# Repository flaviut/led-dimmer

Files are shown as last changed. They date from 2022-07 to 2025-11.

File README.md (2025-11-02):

# IoT RGBWW strip dimmer

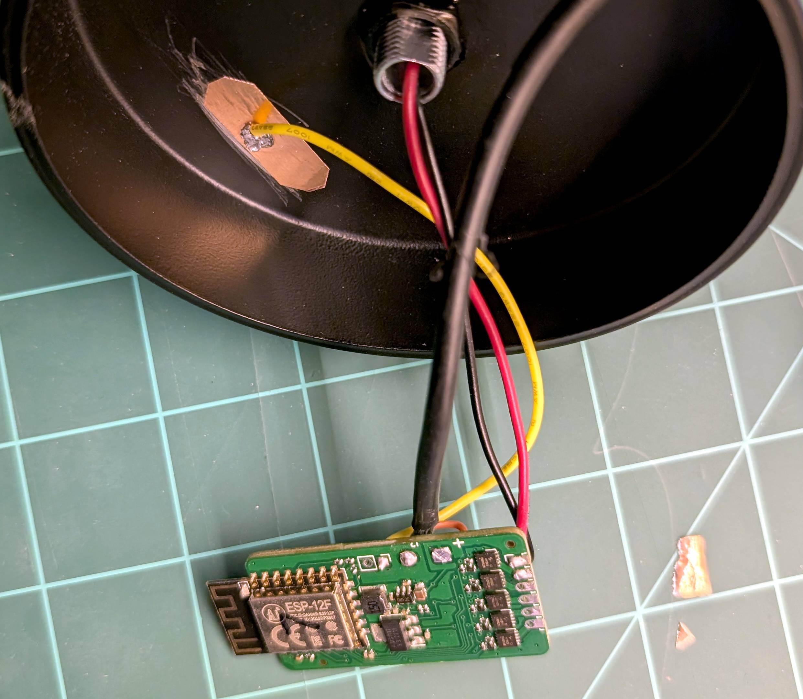
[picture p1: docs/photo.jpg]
photo of dimmer


Designed for use with ESPHome, this project is a compact & powerful dimmer for all LED strips. The primary goal was low cost, in the most compact package possible. For scale, the picture above was taken on a 1 inch grid.

This is intended as a substitute for the poorly-designed Magic Home LED strip controllers.

Note: the yellow wire in the photo does not work as a capacitive touch sensor, that was a failed experiment.

## Features

- Up to 5 lighting channels
- Support for voltages between 5V and 24V
- Up to 4A per channel. Outputs can be paralleled.
- Reasonable efficiency: approx. 200mW standby power draw.
- Low cost, PCB is about $6/ea manufactured at qty 10, or about $4.30/ea at qty 30.

## Description

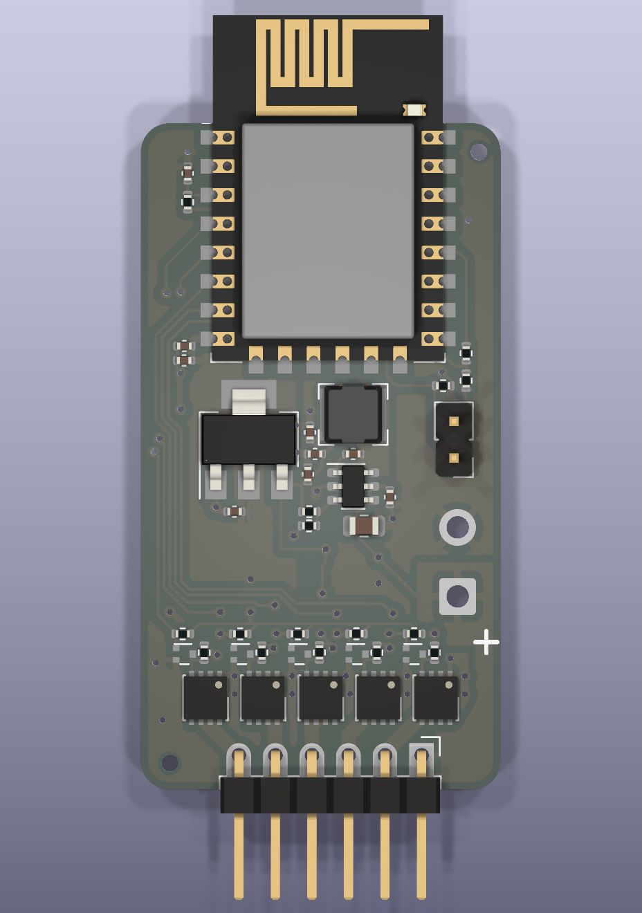
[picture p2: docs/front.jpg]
front

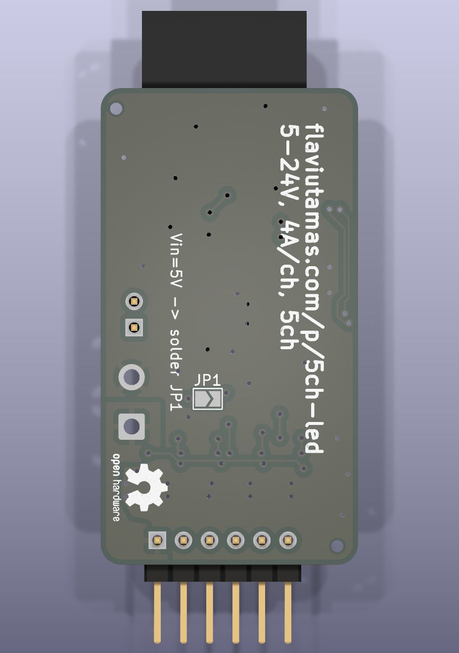
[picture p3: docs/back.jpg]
back

[Schematic](./docs/schematic.pdf)

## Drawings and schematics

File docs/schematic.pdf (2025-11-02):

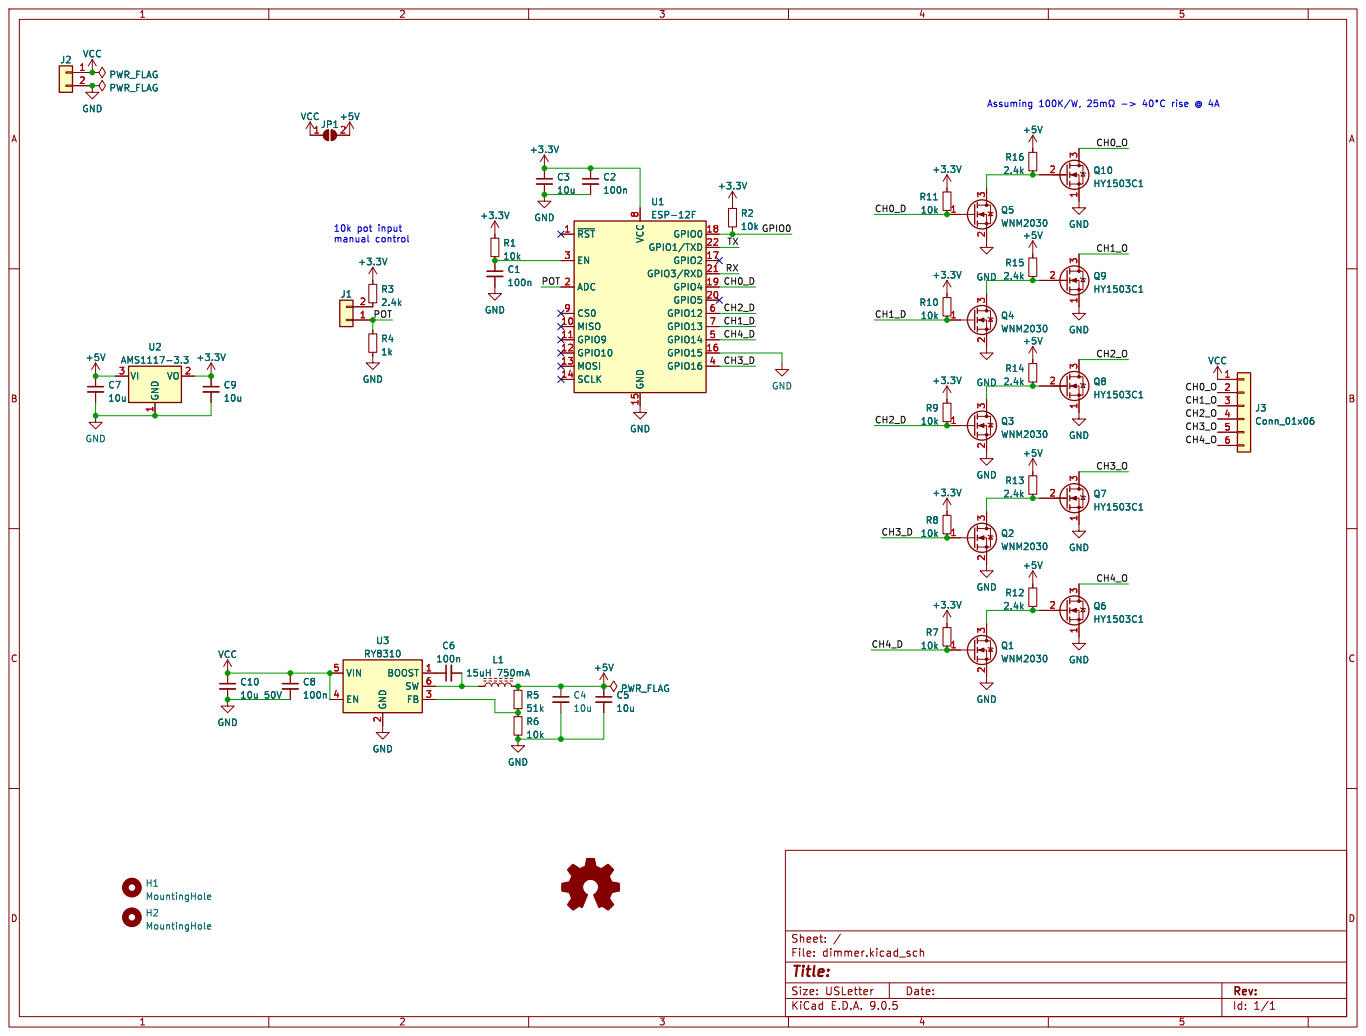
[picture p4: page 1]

Id: 1/1 Title: File: dimmer.kicad_sch Sheet: /

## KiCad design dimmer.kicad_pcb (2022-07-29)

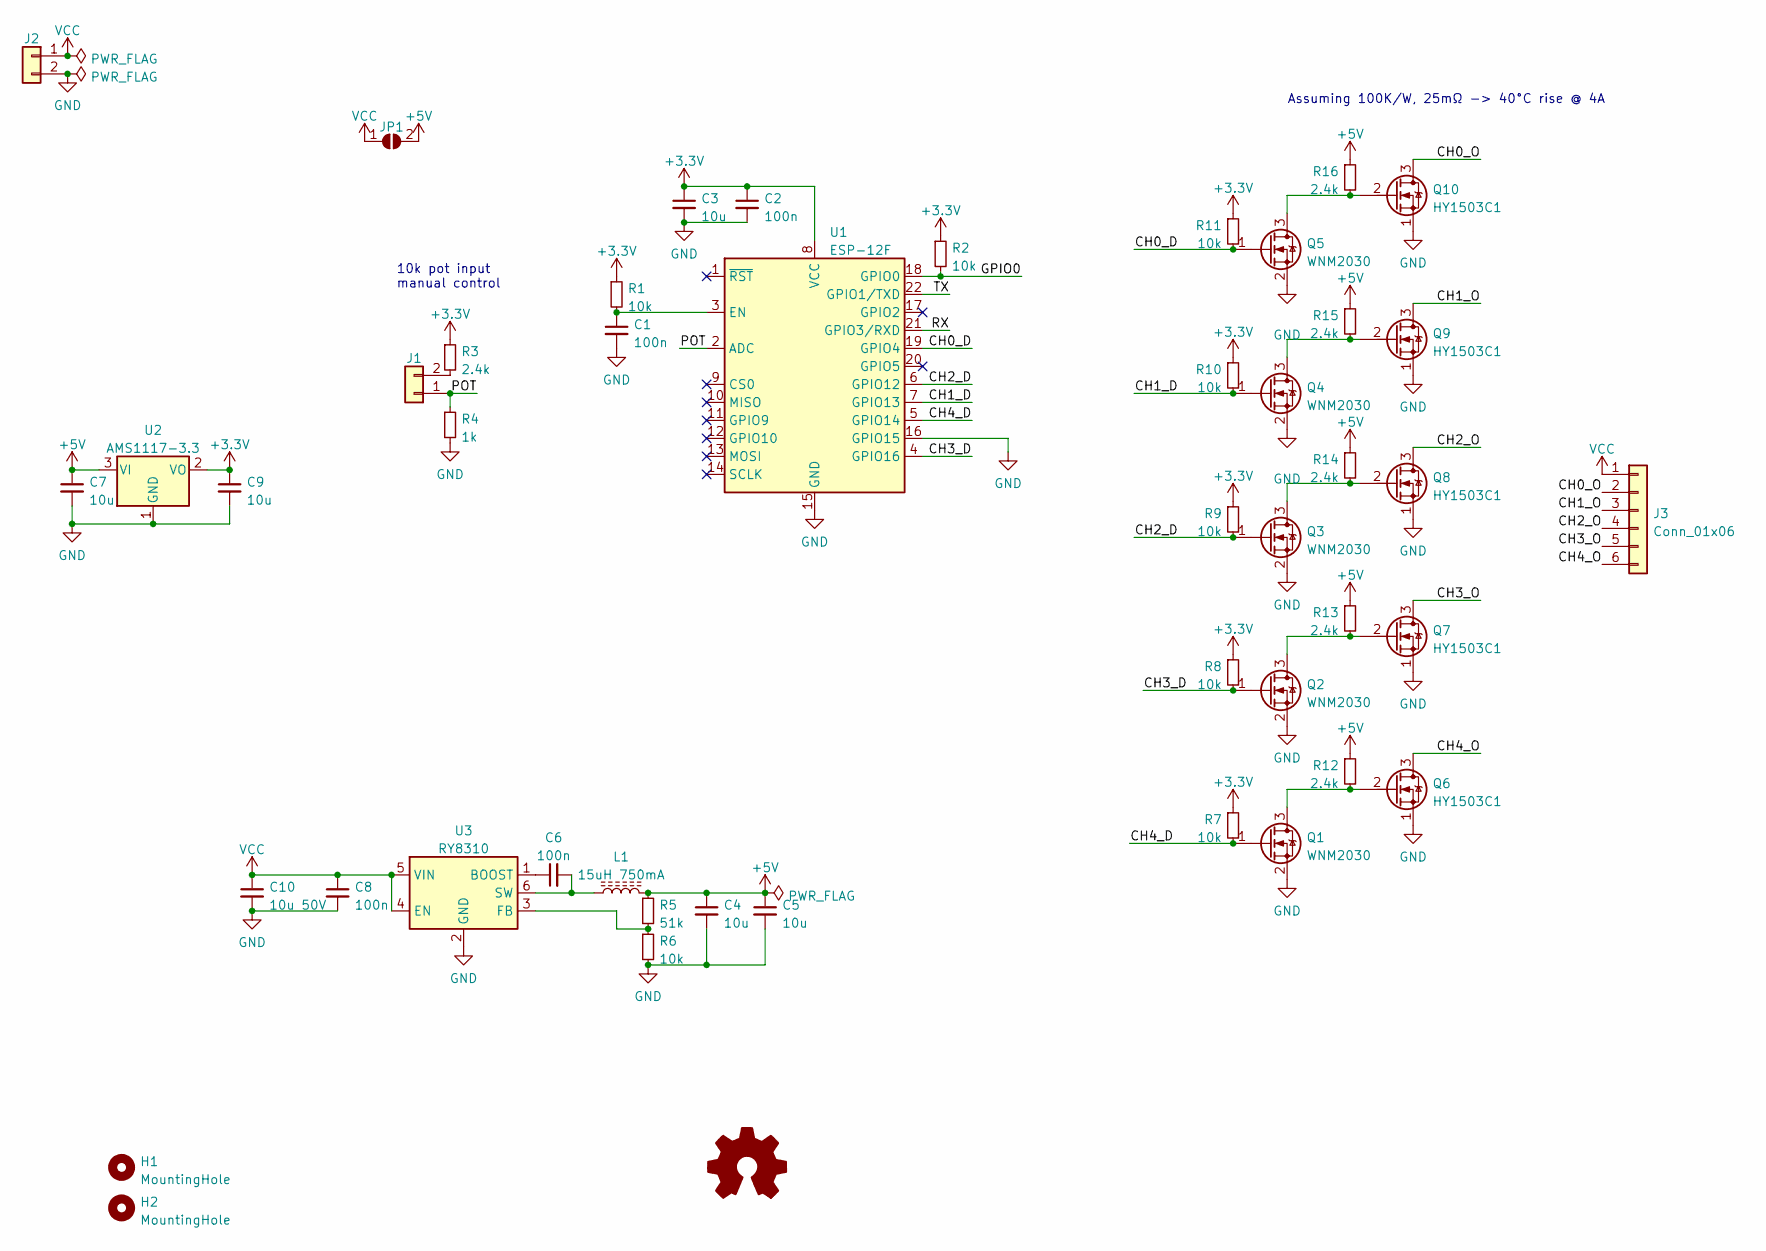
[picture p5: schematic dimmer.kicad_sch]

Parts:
C1, C2, C6, C8: 100n; C_0402_1005Metric; LCSC C307331
C3, C4, C5, C7, C9: 10u; C_0402_1005Metric; LCSC C15525
C10: 10u 50V; C_0805_2012Metric; LCSC C440198
H1, H2: MountingHole; ToolingHole
J1: Conn_01x02; PinHeader_1x02_P2.54mm_Vertical
J2: Conn_01x02; SolderWire-0.75sqmm_1x02_P4.8mm_D1.25mm_OD2.3mm
J3: Conn_01x06; PinHeader_1x06_P2.54mm_Horizontal
JP1: SolderJumper_2_Open; SolderJumper-2_P1.3mm_Open_TrianglePad1.0x1.5mm
L1: 15uH 750mA; L_Bourns-SRN4018; LCSC C167837
LOGO1: Logo_Open_Hardware_Small; OSHW-Logo2_7.3x6mm_SilkScreen
Q1, Q2, Q3, Q4, Q5: WNM2030; SOT-723; LCSC C239769
Q6, Q7, Q8, Q9, Q10: HY1503C1; DFN-8-1EP_3x3mm_P0.65mm_EP2x2.4mm; LCSC C315567
R1, R2, R6, R7, R8, R9, R10, R11: 10k; R_0402_1005Metric; LCSC C25744
R3, R12, R13, R14, R15, R16: 2.4k; R_0402_1005Metric; LCSC C25882
R4: 1k; R_0402_1005Metric; LCSC C11702
R5: 51k; R_0402_1005Metric; LCSC C25794
U1: ESP-12F; ESP-12E; LCSC C82891
U2: AMS1117-3.3; SOT-223-3_TabPin2; LCSC C6186
U3: RY8310; TSOT-23-6; LCSC C370876

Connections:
+3.3V: C2.1, C3.1, C9.1, R1.1, R2.1, R3.1, R7.1, R8.1, R9.1, R10.1, R11.1, U1.8 (VCC), U2.2 (VO)
+5V: C4.1, C5.1, C7.1, JP1.2 (B), L1.2, R5.1, R12.1, R13.1, R14.1, R15.1, R16.1, U2.3 (VI)
/CH0_D: Q5.1 (G), R11.2, U1.19 (GPIO4)
/CH0_O: J3.2, Q10.3 (D)
/CH1_D: Q4.1 (G), R10.2, U1.7 (GPIO13)
/CH1_O: J3.3, Q9.3 (D)
/CH2_D: Q3.1 (G), R9.2, U1.6 (GPIO12)
/CH2_O: J3.4, Q8.3 (D)
/CH3_D: Q2.1 (G), R8.2, U1.4 (GPIO16)
/CH3_O: J3.5, Q7.3 (D)
/CH4_D: Q1.1 (G), R7.2, U1.5 (GPIO14)
/CH4_O: J3.6, Q6.3 (D)
/GPIO0: R2.2, U1.18 (GPIO0)
/POT: J1.1, R4.1, U1.2 (ADC)
/RX: U1.21 (GPIO3/RXD)
/TX: U1.22 (GPIO1/TXD)
GND: C1.2, C2.2, C3.2, C4.2, C5.2, C7.2, C8.2, C9.2, C10.2, J2.2, Q1.2 (S), Q2.2 (S), Q3.2 (S), Q4.2 (S), Q5.2 (S), Q6.1 (S), Q7.1 (S), Q8.1 (S), Q9.1 (S), Q10.1 (S), R4.2, R6.2, U1.15 (GND), U1.16 (GPIO15), U2.1 (GND), U3.2 (GND)
unnamed: C1.1, R1.2, U1.3 (EN)
unnamed: C6.1, U3.1 (BOOST)
unnamed: C6.2, L1.1, U3.6 (SW)
unnamed: J1.2, R3.2
unnamed: Q1.3 (D), Q6.2 (G), R12.2
unnamed: Q2.3 (D), Q7.2 (G), R13.2
unnamed: Q3.3 (D), Q8.2 (G), R14.2
unnamed: Q4.3 (D), Q9.2 (G), R15.2
unnamed: Q5.3 (D), Q10.2 (G), R16.2
unnamed: R5.2, R6.1, U3.3 (FB)
VCC: C8.1, C10.1, J2.1, J3.1, JP1.1 (A), U3.4 (EN), U3.5 (VIN)

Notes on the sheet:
Assuming 100K/W, 25mΩ -> 40°C rise @ 4A
10k pot input manual control

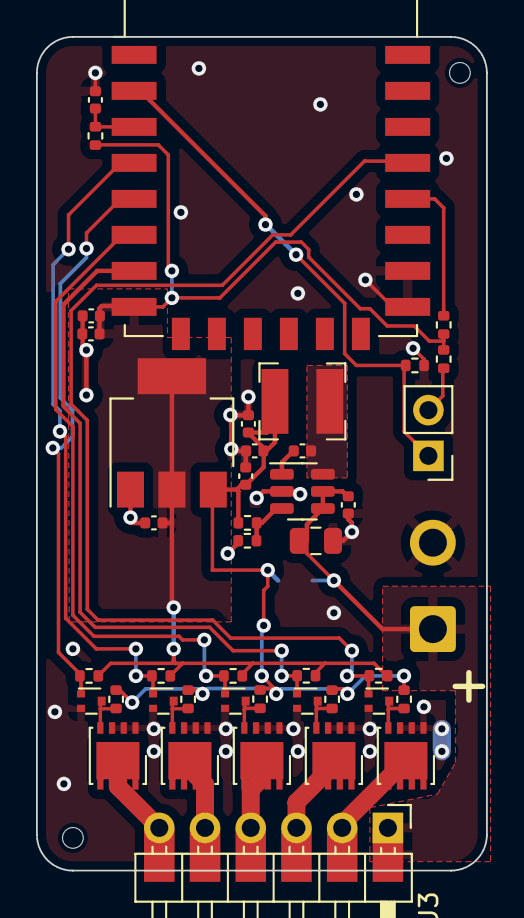
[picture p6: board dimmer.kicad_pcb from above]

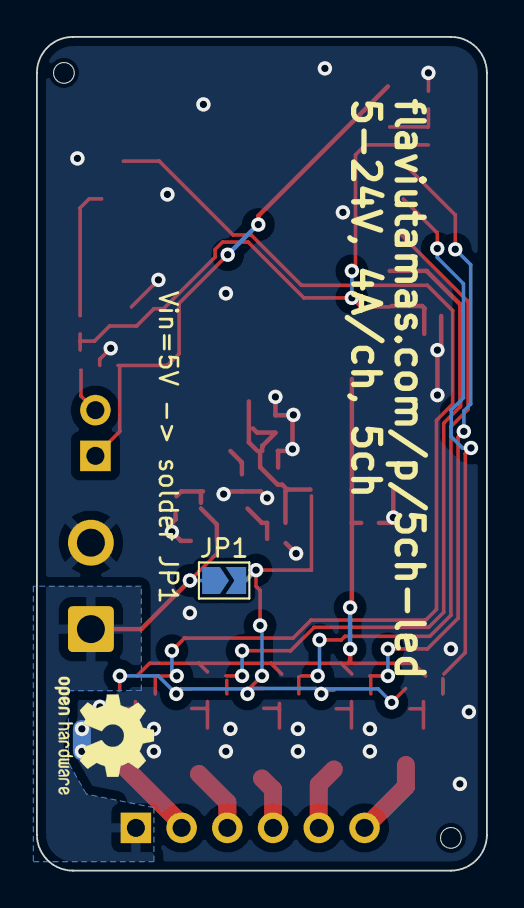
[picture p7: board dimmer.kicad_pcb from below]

Board: 2 copper layers, 25.0 x 46.3 mm, 47 parts (2 on the bottom side), 26 nets.

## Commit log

2022-04-03 Switch to buck & go to production!
    [dimmer.kicad_pcb, dimmer.kicad_sch]
2022-07-02 Simplify design
    [dimmer.kicad_pcb, dimmer.kicad_sch]
2022-07-17 Remove extra LCSC Part property
    [dimmer.kicad_sch]
2022-07-25 Update for in-stock parts
    [dimmer.kicad_sch]
2022-07-29 Disconnect CH0 from on-board LED
    [dimmer.kicad_pcb, dimmer.kicad_sch]
2022-07-29 Increase 3.3V regulator pad size
    [dimmer.kicad_pcb, dimmer.kicad_sch]
2022-07-29 Add tooling holes
    [dimmer.kicad_pcb, dimmer.kicad_sch]
